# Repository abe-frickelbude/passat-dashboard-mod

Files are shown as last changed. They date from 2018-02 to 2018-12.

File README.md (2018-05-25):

# Utilities for the VW Passat (3BG) instrument panel backlight modification project

## adc-serial-monitor

* Written with SpringBoot and Swing
* Provides:
  * A basic "oscilloscope" for AVR ADC input visualization along with some simple signal filtering options
  * A visual controller for RGB(W) programmable LED strips

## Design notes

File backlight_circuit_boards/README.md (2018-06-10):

# Passat 3BG instrument panel backlight circuits

## Center gauge backlight

* Consists of 4x SK6812 RGBW LEDs along with decoupling capacitors
* Custom board, fits existing compartment in the instrument panel's "light mask"
* The DXF file contains the board outline

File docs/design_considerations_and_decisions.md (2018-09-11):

# Design considerations and decisions

## Gauge backlights

## Gauge display backlights

## Center (Multifunction) Display backlight

* It has been experimentally determined that the MFD is a white-on-blue LCD. Apparently the brain-dead morons @VW/Bosch
  couldn't be arsed into using a display with neutral colors (e.g. usual white/transparent on gray), and 
  subsequently used red LEDs to back-light the display instead. The blue background acts as a filter, hence most of the
  background color is cancelled out while the text is red-tinted. 

* The best option here seems to be to provide a >cold< white backlight and optionally tint it with a blue component.
  This will result a "neutral", i.e. original white-on-blue image which will then hopefully harmonize with the other
  backlight colors.

* For practical reasons, the replacement backlight will be a light-guide (salvaged from an old TFT display) which
  is edge-lit by 3 to 4 WS2812s (making a replacement for the original whopping 15 LEDs proved too difficult, and it
  has been experimentally proven that the light-guide version provides sufficient brightness)

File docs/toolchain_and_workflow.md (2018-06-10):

# Toolchains and workflows

## Board development

### Toolchain

* Corel Draw for drafting initial geometry and board dimensions/outlines
* KiCAD
  * Need to install the Sparkfun 3rd party libraries for e.g. WS2812 symbols/footprints
* Inkscape for aux work / final arrangement (see below why)

### Workflow

#### Corel

* Be sure to set all units to mm!
* Add small cross markers for precise placement of components in KiCAD 
* Export board outlines to DXF for import in Kicad
  * Make sure to also set units to mm during export
  * Make sure to select Autocad R12 or earlier as the format - later formats are not recognized by Kicad!  

### KiCAD

* When importing DXF board outlines, set the Layer to "Edge.Cuts", leave other settings as-is
* Be sure to remove any extraneous geometry (e.g. the aforementioned markers once they are no longer needed), as otherwise
  they will interfere with copper flooding etc!
* When declaring keep-out areas, do it on the corresponding copper layer, and make sure to tick the "No copper pour" checkbox
 to also restrict the polygon fill!
* The artwork required for UV exposure should be exported via "Plot", as follows:
  * Use SVG format
  * Only the copper layers
  * Set "Drill marks" to "small"

### Inkscape

* When import, do NOT resize the artwork in any way, as it already has the correct dimensions!

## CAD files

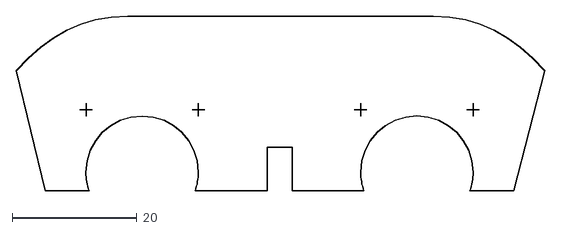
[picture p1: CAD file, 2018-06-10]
backlight_circuit_boards/center_gauges/center_gauge_board_outline.dxf
84.7 x 28.0

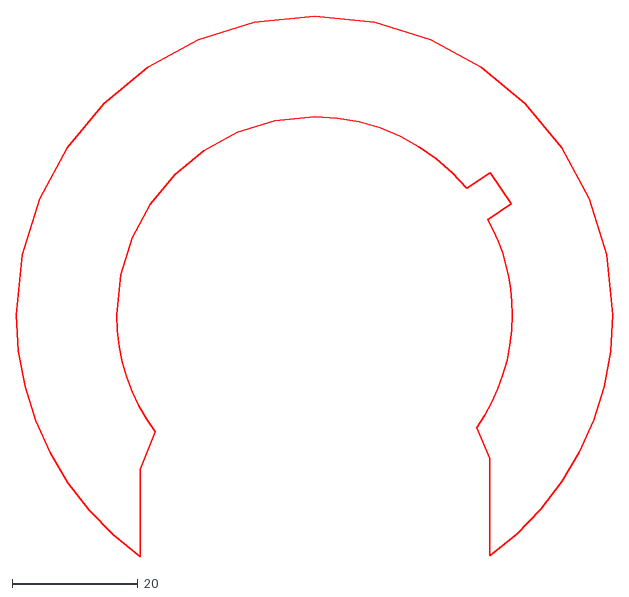
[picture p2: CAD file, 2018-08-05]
backlight_circuit_boards/left_gauge/left_gauge_board_outline.dxf
95.0 x 86.0

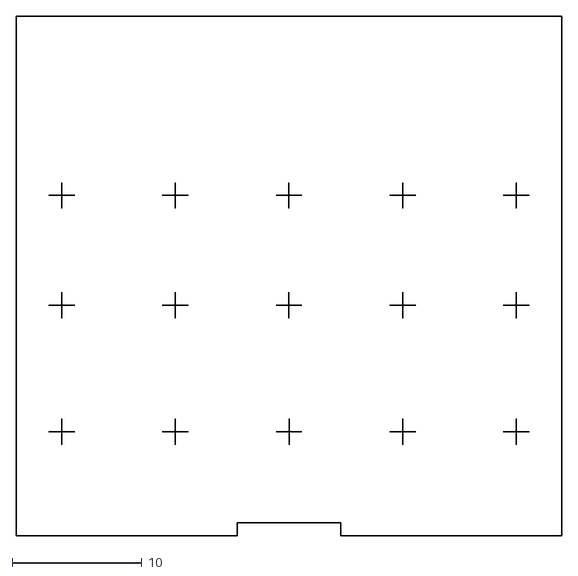
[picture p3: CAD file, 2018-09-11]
backlight_circuit_boards/multi_function_display/mfd_board_outline.dxf
42.0 x 40.0

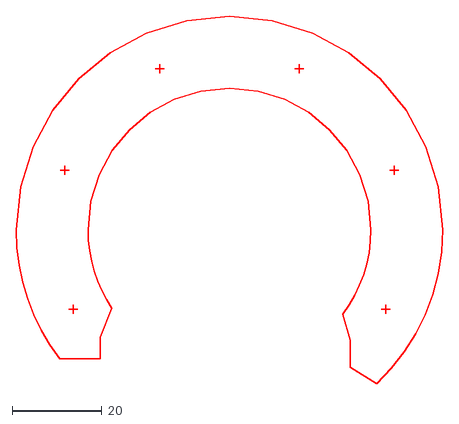
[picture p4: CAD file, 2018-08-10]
backlight_circuit_boards/right_gauge/right_gauge_board_outline.dxf
95.0 x 81.8

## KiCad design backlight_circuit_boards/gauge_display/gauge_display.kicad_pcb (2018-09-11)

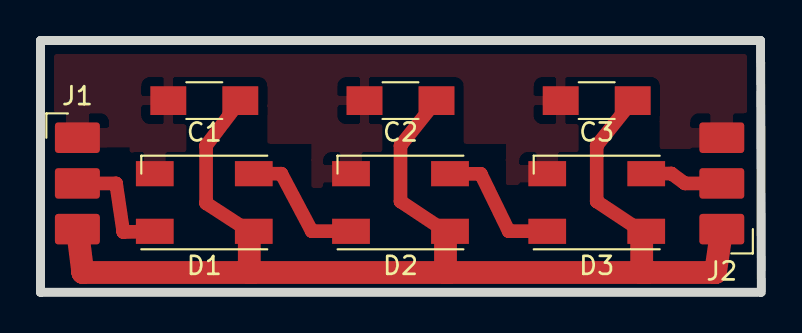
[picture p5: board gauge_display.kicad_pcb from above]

Board: 2 copper layers, 40.0 x 14.0 mm, 8 parts (0 on the bottom side), 6 nets.

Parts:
C1, C2, C3: C; C_1206_HandSoldering
D1, D2, D3: WS2812B; LED_WS2812B-PLCC4_HandSoldering
J1, J2: Conn_01x03; wire_solder_pads_1x03_2.5x1.7mm_Pitch2.54mm

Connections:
GND: C1.2, C2.2, C3.2, D1.3, D2.3, D3.3, J1.1, J2.3
unnamed: D1.2, D2.4
unnamed: D1.4, J1.2
unnamed: D2.2, D3.4
unnamed: D3.2, J2.2
VCC: C1.1, C2.1, C3.1, D1.1, D2.1, D3.1, J1.3, J2.1

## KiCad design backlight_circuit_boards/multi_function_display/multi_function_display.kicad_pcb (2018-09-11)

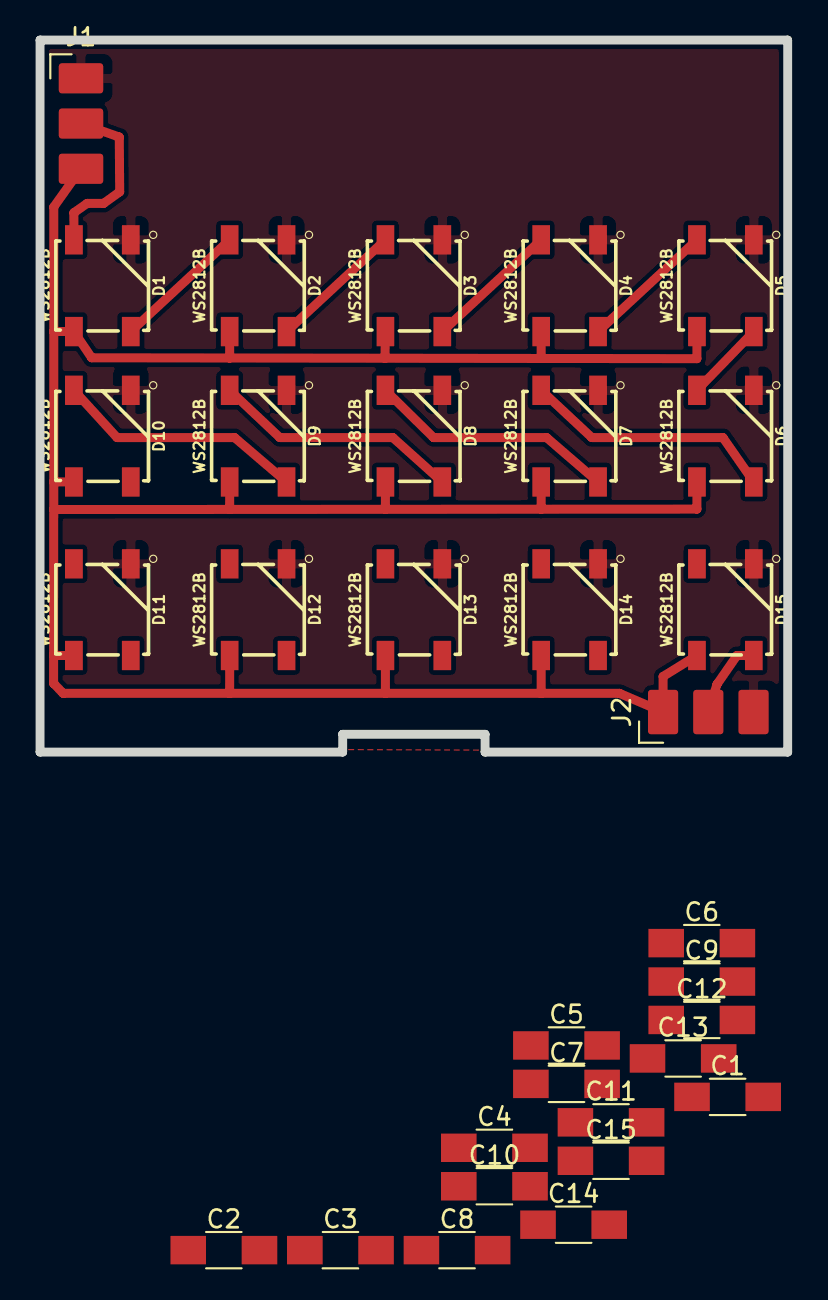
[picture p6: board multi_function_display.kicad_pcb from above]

Board: 2 copper layers, 42.0 x 40.0 mm, 32 parts (0 on the bottom side), 18 nets.

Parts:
C1, C2, C3, C4, C5, C6, C7, C8, C9, C10, C11, C12, C13, C14, C15: 0.1; C_1206_HandSoldering
D1, D2, D3, D4, D5, D6, D7, D8, D9, D10, D11, D12, D13, D14, D15: WS2812B
J1, J2: Conn_01x03; wire_solder_pads_1x03_2.5x1.7mm_Pitch2.54mm

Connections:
GND: C1.2, C2.2, C3.2, C4.2, C5.2, C6.2, C7.2, C8.2, C9.2, C10.2, C11.2, C12.2, C13.2, C14.2, C15.2, D1.3, D2.3, D3.3, D4.3, D5.3, D6.3, D7.3, D8.3, D9.3, D10.3, D11.3, D12.3, D13.3, D14.3, D15.3, J1.1, J2.3
unnamed: D1.2, D2.4
unnamed: D1.4, J1.2
unnamed: D2.2, D3.4
unnamed: D3.2, D4.4
unnamed: D4.2, D5.4
unnamed: D5.2, D6.4
unnamed: D6.2, D7.4
unnamed: D7.2, D8.4
unnamed: D8.2, D9.4
unnamed: D10.2, D11.4
unnamed: D9.2, D10.4
unnamed: D11.2, D12.4
unnamed: D12.2, D13.4
unnamed: D13.2, D14.4
unnamed: D14.2, D15.4
unnamed: D15.2, J2.2
VCC: C1.1, C2.1, C3.1, C4.1, C5.1, C6.1, C7.1, C8.1, C9.1, C10.1, C11.1, C12.1, C13.1, C14.1, C15.1, D1.1, D2.1, D3.1, D4.1, D5.1, D6.1, D7.1, D8.1, D9.1, D10.1, D11.1, D12.1, D13.1, D14.1, D15.1, J1.3, J2.1

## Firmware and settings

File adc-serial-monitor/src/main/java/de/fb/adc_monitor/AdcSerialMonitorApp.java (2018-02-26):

package de.fb.adc_monitor;

import java.awt.EventQueue;
import javax.swing.UIManager;
import org.slf4j.*;
import org.slf4j.bridge.SLF4JBridgeHandler;
import org.springframework.boot.SpringApplication;
import org.springframework.context.ConfigurableApplicationContext;
import com.bulenkov.darcula.DarculaLaf;
import de.fb.adc_monitor.config.AppContextConfiguration;
import de.fb.adc_monitor.view.*;

/**
 * This class essentially ties together Spring application context initialization and any auxiliary initialization of
 * Swing etc, and is ultimately responsible for setting up the Swing GUI.
 * 
 * @author Ibragim Kuliev
 *
 */
public class AdcSerialMonitorApp {

    private static final Logger log = LoggerFactory.getLogger(AdcSerialMonitorApp.class);

    // singleton application context instance
    private static ConfigurableApplicationContext appContext;

    public static void main(final String[] args) {
        configureLogging();
        configureSwingLookAndFeel();
        initializeApp(args);
    }

    private static void initializeApp(final String[] args) {
        /*
         * The section below might now be completely self-explanatory, so:
         * Basically the >run< sequence actually consists of two steps - the first one has to initialize the Spring
         * app context along with all SpringBoot magic, and the second one then initializes and displays the Swing UI.
         * For this to work, we need to retrieve the app context from the initialized SpringApplication instance, hence
         * the line below.
         */
        try {
            appContext = SpringApplication.run(AppContextConfiguration.class, args);
            appContext.registerShutdownHook();

            EventQueue.invokeLater(() -> {
                try {
                    // show the UI windows
                    final MainWindow mainWindow = appContext.getBean(MainWindow.class);
                    final ControlWindow controlWindow = appContext.getBean(ControlWindow.class);
                    final LogWindow logWindow = appContext.getBean(LogWindow.class);

                    UILayouter uiLayouter = appContext.getBean(UILayouter.class);

                    uiLayouter.layoutWindows(false, 0.7f, 0.6f);
                    mainWindow.setVisible(true);
                    controlWindow.setVisible(true);
                    logWindow.setVisible(true);

                } catch (Exception ex) {
                    log.error(ex.getMessage(), ex);
                    System.exit(-1);
                }
            });
        } catch (Exception ex) {
            log.error(ex.getMessage(), ex);
            System.exit(-1);
        }
    }

    private static void configureLogging() {
        // route java.util.logging through SLF4J
        SLF4JBridgeHandler.removeHandlersForRootLogger();
        SLF4JBridgeHandler.install();
    }

    /*
     * Swing "platform look and feel" has to be set PRIOR to any component initialization, otherwise it will have no
     * effect!
     */
    private static void configureSwingLookAndFeel() {
        try {
            UIManager.setLookAndFeel(new DarculaLaf());
        } catch (Exception ex) {
            // Note: this is not an unrecoverable exception - the application will just use the default look and feel!
            log.error(ex.getMessage(), ex);
        }
    }
}

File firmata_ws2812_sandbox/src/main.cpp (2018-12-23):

////////////////////////////////////////////////////////////////////////////////
////////////////////////////////////////////////////////////////////////////////

////////////////////////////////////////////////////////////////////////////////
////////////////////////////////////////////////////////////////////////////////

#include <math.h>
#include <Arduino.h>
#include <Firmata.h>
#include <SoftwareSerial.h>

#include "fab_led.h"

// custom SysEx commands for pixel operations
const byte PIXEL_COMMAND = 0x40;

const byte SET_NUM_PIXELS = 0x01;
const byte SET_PIXEL = 0x02;
const byte RESET_PIXEL = 0x03;
const byte RESET_ALL = 0x04;
const byte SHOW_PIXELS = 0x05;

const byte ANALOG_READ_COMMAND = 0x41;

// analog input
const byte ANALOG_INPUT_PIN = PIN_A1;

const float ADC_SCALING_FACTOR = 255.0f / 1023.0f;

// --------------------- LED state ---------------------------

// maximum allowed number of pixels
const uint8_t NUM_PIXELS = 64;

// pixel state array
rgbw pixels[NUM_PIXELS] = {};

// current number of active pixels
volatile int numPixels = 0;

// used to watch for data modifications in the main loop
volatile bool stateChanged = false;

// SK6812 strip on PORT D, pin 2
sk6812b<D, 2> strip;

// ------------------------------------------------------------

void sendAnalog(byte pin, uint16_t value);
byte scaleAnalogValue(uint16_t value);

void resetPixels();
void setPixel(byte index, byte r, byte g, byte b, byte w);
void sysexCallback(byte command, byte argc, byte *argv);
void pixelCallback(byte command, byte argc, byte *argv);

void setup()
{
    Firmata.setFirmwareNameAndVersion("WS2812 Sandbox",
                                      FIRMATA_FIRMWARE_MAJOR_VERSION,
                                      FIRMATA_FIRMWARE_MINOR_VERSION);

    Firmata.attach(START_SYSEX, sysexCallback);
    Firmata.begin(115200); // ?! Can't use a previously defined uint16_t constant here!

    pinMode(LED_BUILTIN, OUTPUT);
    //pinMode(ANALOG_INPUT_PIN, INPUT);

    // initial reset
    strip.clear(NUM_PIXELS);
}

void loop()
{
    // process input commands
    while (Firmata.available())
    {
        Firmata.processInput();
    }

    // update and send analog input(s)
    //Firmata.sendAnalog(ANALOG_INPUT_PIN, scaleAnalogValue(analogRead(ANALOG_INPUT_PIN)));
    Firmata.sendAnalog(ANALOG_INPUT_PIN, analogRead(ANALOG_INPUT_PIN));
    //sendAnalog(ANALOG_INPUT_PIN, analogRead(ANALOG_INPUT_PIN));

    if (stateChanged)
    {
        //strip.clear(numPixels);
        strip.sendPixels(numPixels, pixels);
        stateChanged = false;
    }
}

byte scaleAnalogValue(uint16_t value)
{
    return static_cast<byte>(value * ADC_SCALING_FACTOR);
}

void sendAnalog(byte pin, uint16_t value)
{

    Firmata.startSysex();
    Firmata.write(ANALOG_READ_COMMAND);
    Firmata.write(pin);
    Firmata.sendValueAsTwo7bitBytes(value);
    Firmata.endSysex();
}

void sysexCallback(byte command, byte argc, byte *argv)
{
    switch (command)
    {
    case PIXEL_COMMAND:
        if (argc < 1)
            return;
        // pass all pixel commands to custom callback
        pixelCallback(argv[0], argc - 1, argv + 1);
        break;

    default:
        break;
    }
}

void pixelCallback(byte command, byte argc, byte *argv)
{
    switch (command)
    {

    case SET_NUM_PIXELS:
    {
        numPixels = argv[0] & 0x7F;
    }
    break;

    case SET_PIXEL:
    {
        uint8_t index = argv[0] & 0x7F;
        uint8_t r = (argv[1] & 0x7F) | ((argv[2] & 0x7F) << 7);
        uint8_t g = (argv[3] & 0x7F) | ((argv[4] & 0x7F) << 7);
        uint8_t b = (argv[5] & 0x7F) | ((argv[6] & 0x7F) << 7);
        uint8_t w = (argv[7] & 0x7F) | ((argv[8] & 0x7F) << 7);
        setPixel(index, r, g, b, w);
    }
    break;

    case RESET_PIXEL:
    {
        uint8_t index = argv[0] & 0x7F;
        setPixel(index, 0x00, 0x00, 0x00, 0x00);
    }
    break;

    case RESET_ALL:
    {
        //strip.clear(numPixels);
        strip.clear(NUM_PIXELS);
        break;
    }

    case SHOW_PIXELS:
    {
        stateChanged = true;
        break;
    }
    }
}

void setPixel(byte index, byte r, byte g, byte b, byte w)
{
    pixels[index].r = r;
    pixels[index].g = g;
    pixels[index].b = b;
    pixels[index].w = w;
}

void resetPixels()
{
    for (int i = 0; i < NUM_PIXELS; i++)
    {
        pixels[i].r = pixels[i].g = pixels[i].b = pixels[i].w = 0x00;
    }
}

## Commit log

2018-01-09 WIP port of old Kalman filter processing sketch to processing 3.x
    - Maven build is busted right now because the mvn repo "processing-core"
    and "processing-serial" artifacts are messed up, will need to rely on
    local processing 3.x installation instead <sigh...>
2018-01-13 Forked base code from spring-swing-skeleton, added some dependencies
2018-01-21 WIP arduino uplink
2018-01-25 Migrated to SpringBoot
    - Added some fancy SpringBoot gubbinz
    - WIP: JAnsiTextPane for even moar fancy gubbinz -> support SpringBoot's
    ANSI output in Swing views
    - Window / Controller code: added error message box when no serial ports
    can be detected
    [AdcSerialMonitorApp.java, ArduinoLinkService.java]
2018-01-30 Fixed some issues
    - autoscrolling now works correctly in JConsoleLogPane / JAnsiTextPane
    - added auto-clear to JConsoleLogPane
    - moved app context instance in the main app class (app context
    reference was being closed prematurely..)
    [AdcSerialMonitorApp.java]
2018-02-01 Added AdcMonitorViewTest for visualizing various Kalman filter settings
2018-02-03 Basic UI stuff for filter experiments
2018-02-03 Added different filters for further experiments
2018-02-06 Arduino code for reading ADC over serial link
2018-02-12 Added filtering and improved refresh rate control
2018-02-13 Basic signal visualization now done
    - added optional pre/post filter thresholding
    - Simple exponential filter seems to be the most suitable, at ~ 0.2
    smoothing factor and ~ 25-30 mV post-filter thresholding operation
2018-02-27 Renamed application to "Arduino Sandbox"
2018-02-27 Renamed base package to "arduino_sandbox"
2018-02-28 WIP RGWB LED color group widget
2018-03-03 WIP: LedGroupColorSwatch
2018-03-24 WIP LedGroupColorSwatch, using new TinyButton/TinyButtonGroup classes
2018-03-29 WIP LED group configuration
2018-05-13 Fixed some rendering bugs in Dial
    - Integrated rotary knobs into RgbwSwatchGroup widget
    [SandboxPanel.java]
2018-05-14 WIP Basic LED sandbox integration
    - load / save configuration completed
    - renamed some classes for better clarity
2018-05-15 Basic scaffold for SK6812 RGBW led strip experimental controller
2018-05-25 remove obsolete adc-monitor sub-project
2018-05-25 remove obsolete arduino-serial-adc subproject
2018-05-27 Basic RGBW controller tests OK, the firmware is roughly operational - WIP pixel positions are inconsistent, trying to figure out why every 2nd pixel is skipped by the firmware!
    [AdcTracerController.java, ArdulinkUplink.java, LedSandboxController.java]
2018-05-31 Basic LED controller functionality is now operational
2018-06-03 Minor improvements to UI
    - Added change listener to ColorSwatch's color chooser to
    enabled on-the-fly updates to colors while the color chooser
    dialog is still open
    - Removed obsolete JColorSwatch and BiColorSwatch
    - ZoomableChartView migrated to the new ColorSwatch
    - Added manual LED re-init capability to LED control panel
2018-06-10 Create boards
2018-06-10 WIP center gauge backlight circuit board
    [center_gauge_board_outline.dxf, center_gauges_backlight.kicad_pcb, center_gauges_backlight.sch]
2018-06-10 Improved copper fill
    [center_gauges_backlight.kicad_pcb]
2018-08-05 Added subdirectories, WIP left gauge PCB
    [center_gauge_board_outline.dxf, center_gauges_backlight.kicad_pcb, center_gauges_backlight.sch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]
2018-08-06 Left gauge PCB done, WIP right gauge PCB, switched to KC 5
    [left_gauge-2018-08-06-18-20-27.sch, left_gauge.kicad_pcb, right_gauge_board_outline.dxf]
2018-08-10 WIP right gauge PCB
    [right_gauge.kicad_pcb, right_gauge.sch, right_gauge_board_outline.dxf]
2018-08-13 improvements to all boards
    [center_gauges_backlight-2018-08-13-00-07-40.sch, center_gauges_backlight.kicad_pcb, left_gauge.kicad_pcb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]
2018-09-07 Added gauge clock/km display boards
    [center_gauges_backlight.kicad_pcb, gauge_display.kicad_pcb, gauge_display.sch]
2018-09-07 Make clock/km board a little smaller, built combined artwork SVG
    [gauge_display.kicad_pcb]
2018-09-08 Small improvements to thermal relief on all PCBs
    [center_gauges_backlight.kicad_pcb, left_gauge.kicad_pcb, right_gauge.kicad_pcb]
2018-09-11 added preliminary design docs (WIP)
    [gauge_display.kicad_pcb, mfd_board_outline.dxf, multi_function_display.kicad_pcb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]
2018-11-07 Ported to Java 10 / Spring Boot 2.x
2018-12-23 Switched everything to Firmata (no ArduLink anymore)
    - Added custom message parser & co for retrieving 16-bit ADC values
2018-12-23 Added ADC reads using Firmata
2019-01-19 recent files
    [brightess_control_duty_cycle_vs_voltage.ods]
2019-01-19 WIP pwm simulator
